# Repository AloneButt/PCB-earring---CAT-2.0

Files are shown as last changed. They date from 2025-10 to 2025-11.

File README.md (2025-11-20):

# 🐱 Kitty Blinky Earrings

This project is a **pair of kitty-shaped PCBs** designed as earrings for my beloved wife 💖.  
Each earring is powered by a CR2032 coin cell and blinks two LEDs in an alternating pattern (classic astable multivibrator style 🟡🟢).  

It’s a mix of **electronics + wearable art**, made as a gift 💝.

## 🥂 Shoutout to the sponsor of the project

<p align="center">
  <a href="https://www.pcbway.com/?from=github" target="_blank">
    PCBWay Logo
  </a>
</p>

<p align="center">
  This project was proudly prototyped with support from
  <a href="https://www.pcbway.com/?from=github"><b>PCBWay</b></a>.<br>
  Their precision manufacturing, excellent finish quality, and quick lead times made this build possible.
  Check out their site and PCB manufacturing capabilities and good luck!
</p>

---

## ✨ Features
- Kitty-shaped PCB outline 😺
- Two LEDs blinking one after another (0.5 Hz)
- Powered by a CR2032 battery (≈220 mAh)
- Minimal BOM (two transistors, resistors, capacitors, LEDs, battery holder)
- Works as earrings or just a tiny blinking desk buddy

---

## 🛠️ How It Works
- Simple transistor astable multivibrator  
- No microcontroller, no 555 timer, just pure retro discrete-component charm  
- Each side alternately lights an LED, making the kitty “sparkle”

---

## 🎁 Why?
Because sometimes the best gifts are the ones you solder yourself ❤️

---

## 🧩 Folder Contents (not ready yet)
- `schematic/` → KiCAD schematic files  
- `pcb/` → KiCAD PCB layout (kitty outline!)  
- `gerbers/` → Production files to send to a fab  
- `3d/` → Renders of the finished board  
- `docs/` → Pictures and notes  

---

## ⚡ BOM (Bill of Materials)
| Part | Qty | Notes |
|---|-----|---|
| 2N3904U transistor | 2 | NPN |
| Resistors | 5 | LED current limiting + timing |
| Capacitors | 2 | 10 µF timing caps |
| LEDs | 2 | SMD 0805 (color of choice) |
| CR2032 battery holder | 1 | Top-mount or back-mount |
| PCB | 1 | Kitty shaped 🐾 |

---

## 📸 Preview

## 3D
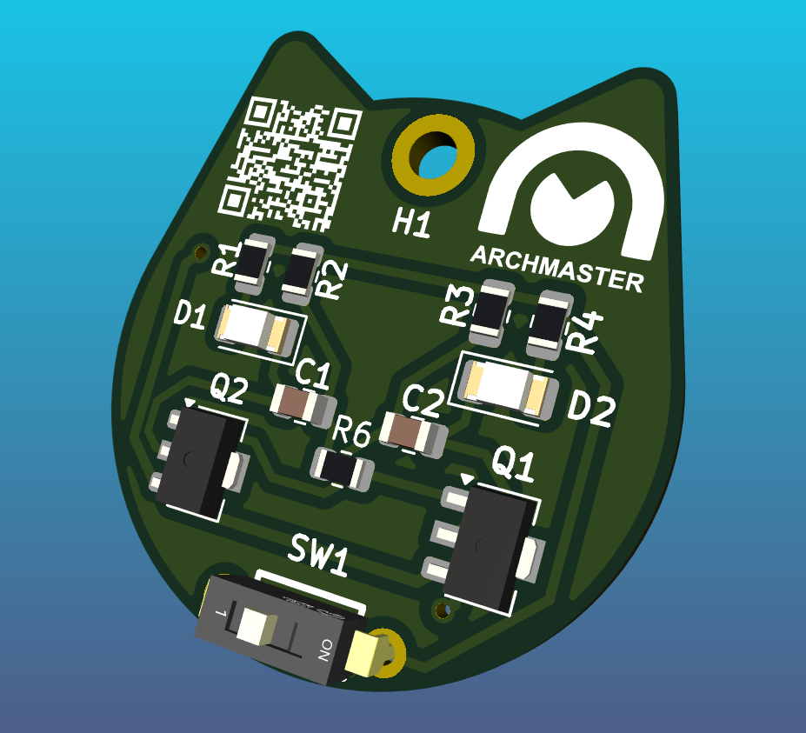
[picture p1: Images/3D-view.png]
3D-View


## PCB
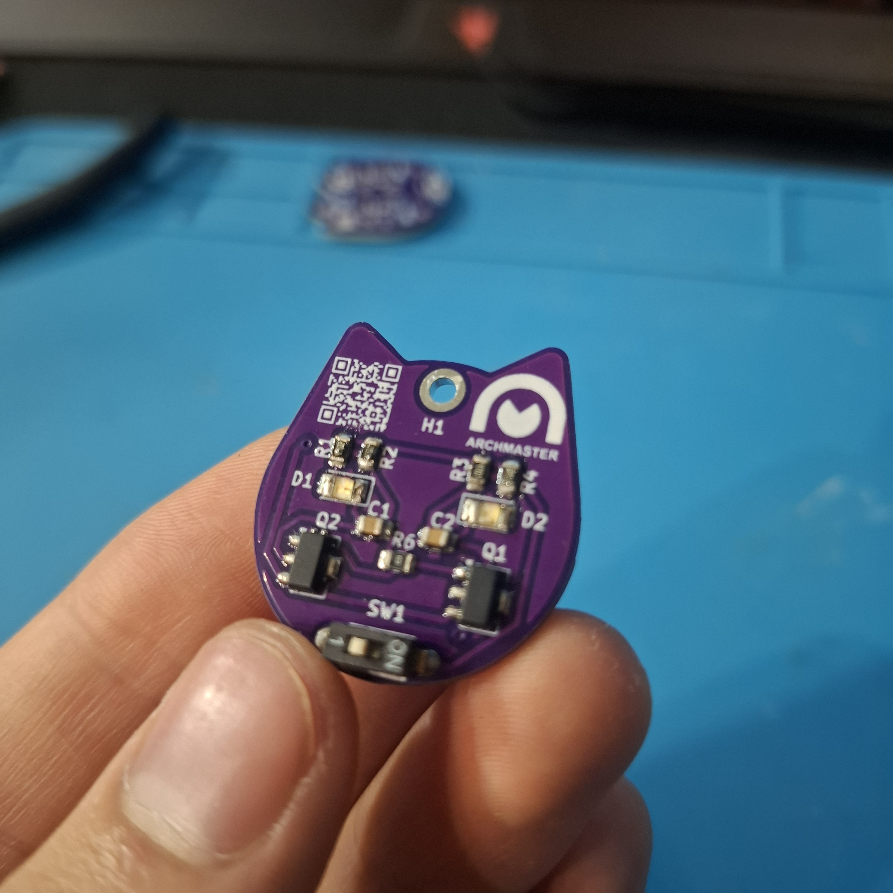
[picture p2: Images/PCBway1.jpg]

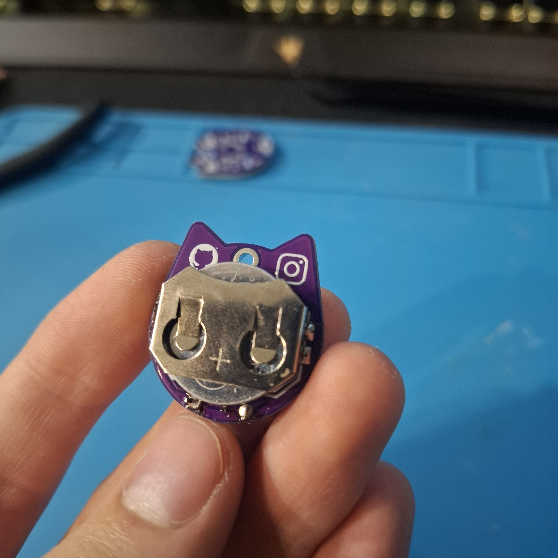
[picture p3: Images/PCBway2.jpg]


## Video
Video (https://www.youtube.com/shorts/Oom2REd-UTQ)

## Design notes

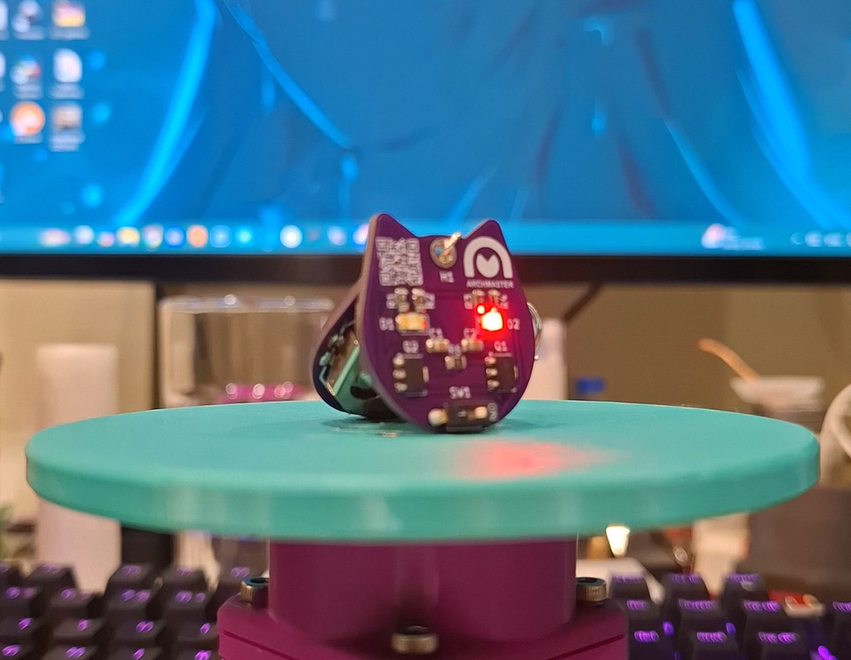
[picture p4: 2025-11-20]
Images/thumbnail.png

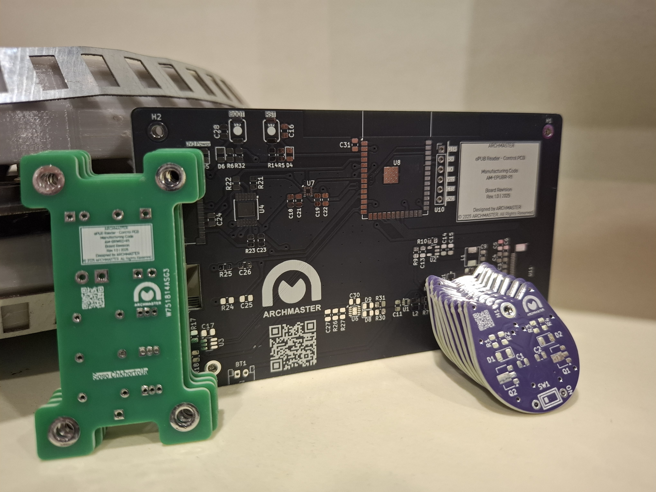
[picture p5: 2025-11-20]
Images/PCBway3.jpg

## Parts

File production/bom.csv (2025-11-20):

Designator | Footprint | Quantity | Value | LCSC Part #
BT1 | BATTERY holder CR2032 SMD | 1 | Battery_Cell
C1, C2 | 0805 | 2 | C_Polarized
D1, D2 | 1206 | 2 | LED
Q1, Q2 | SOT-89-3 | 2 | 2N3904U
R1, R4 | 0805 | 2 | 470R
R2, R3 | 0805 | 2 | 47kR
R6 | 0805 | 1 | 0R (jumper)
SW1 | DIP switch 1P THT | 1 | SW_SPST

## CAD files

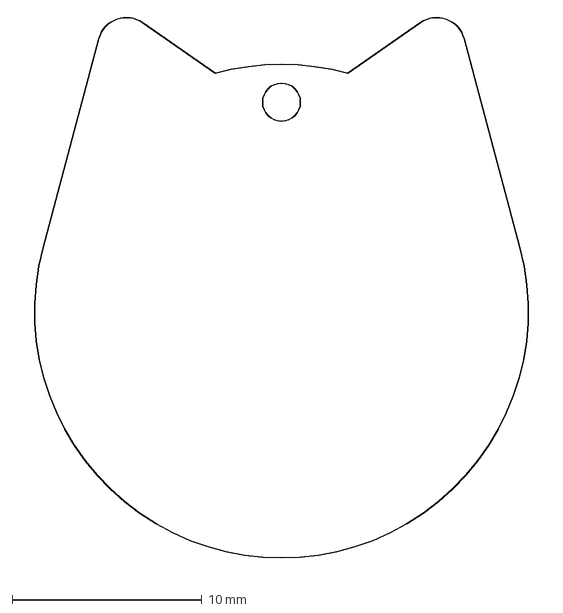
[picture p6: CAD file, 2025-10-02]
Earring - CAT 2.0 outline.dxf
27.9 x 29.3 mm

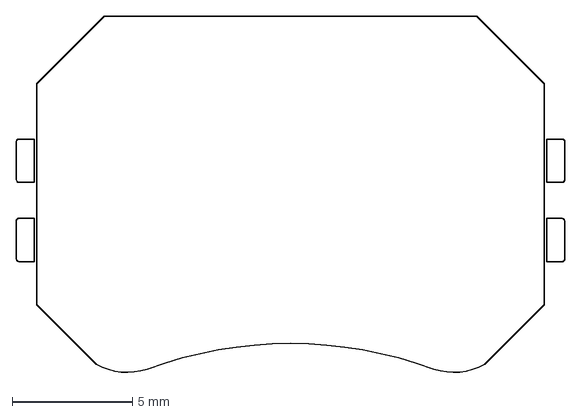
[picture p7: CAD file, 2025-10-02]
Earring - CAT 2.0 BAT outline.dxf
22.8 x 14.9 mm

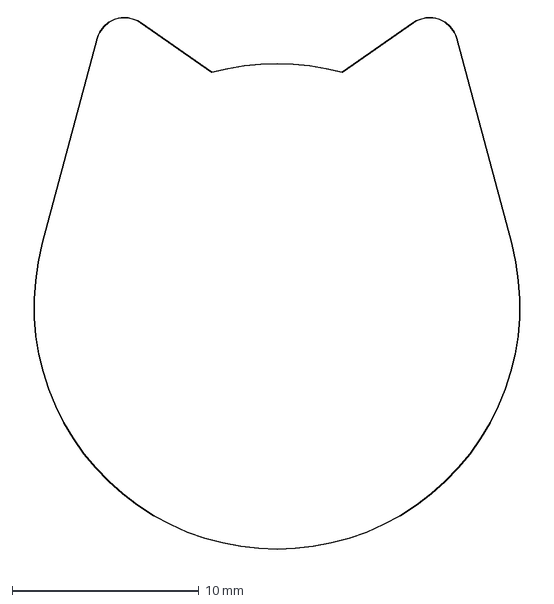
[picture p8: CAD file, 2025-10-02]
Earring - CAT 2.0 outline 2.dxf
27.9 x 29.3 mm

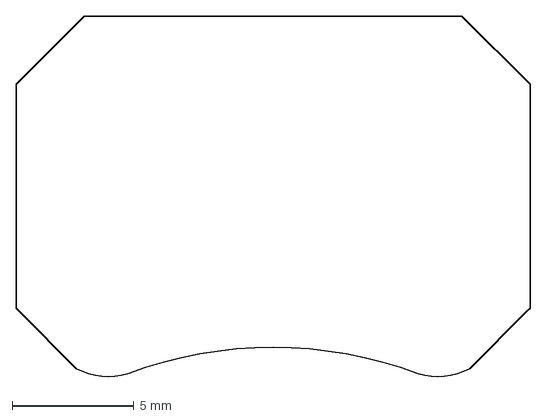
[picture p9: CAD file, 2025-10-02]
Earring - CAT 2.0 BAT outline 2.dxf
21.1 x 14.9 mm

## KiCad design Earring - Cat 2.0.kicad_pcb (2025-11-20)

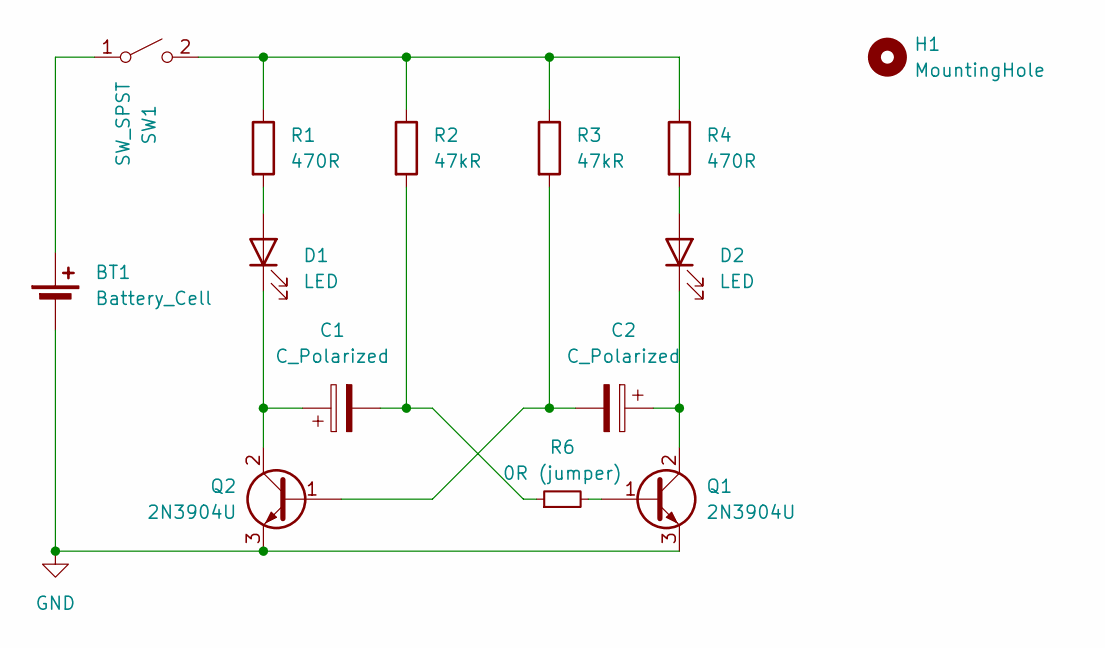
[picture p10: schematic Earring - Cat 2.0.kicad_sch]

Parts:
BT1: Battery_Cell; BATTERY holder CR2032 SMD
C1, C2: C_Polarized; C_0805_2012Metric
D1, D2: LED; LED_1206_3216Metric
H1: MountingHole; MountingHole_2.2mm_M2_DIN965_Pad
Q1, Q2: 2N3904U; SOT-89-3
R1, R4: 470R; R_0805_2012Metric
R2, R3: 47kR; R_0805_2012Metric
R6: 0R (jumper); R_0805_2012Metric
SW1: SW_SPST; DIP switch 1P THT

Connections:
GND: BT1.2 (-), Q1.3 (E), Q2.3 (E)
unnamed: BT1.1 (+), SW1.1 (A)
unnamed: C1.2, R2.2, R6.1
unnamed: D1.2 (A), R1.2
unnamed: C1.1, D1.1 (K), Q2.2 (C)
unnamed: D2.2 (A), R4.2
unnamed: C2.1, D2.1 (K), Q1.2 (C)
unnamed: Q1.1 (B), R6.2
unnamed: C2.2, Q2.1 (B), R3.2
unnamed: R1.1, R2.1, R3.1, R4.1, SW1.2 (B)

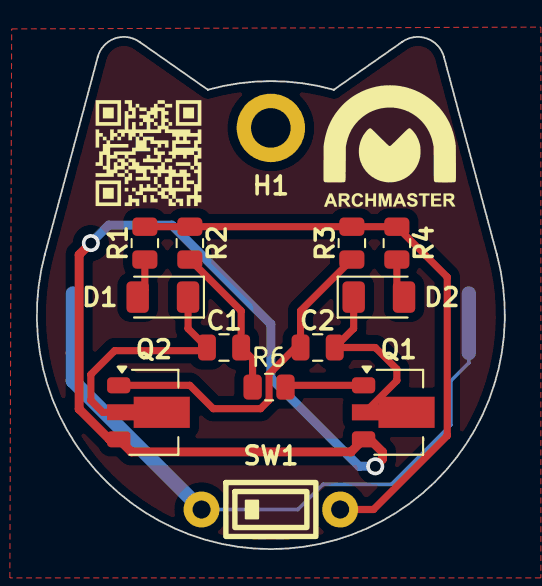
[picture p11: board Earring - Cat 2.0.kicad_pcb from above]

Board: 2 copper layers, 26.0 x 28.5 mm, 14 parts (1 on the bottom side), 10 nets.

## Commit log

2025-10-08 updated the silkscreen
    [Earring - Cat 2.0.kicad_pcb, bom.csv, designators.csv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]
2025-11-20 updated prod and media
    [Earring - Cat 2.0.kicad_pcb, Earring - Cat 2.0.kicad_sch, bom.csv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]
